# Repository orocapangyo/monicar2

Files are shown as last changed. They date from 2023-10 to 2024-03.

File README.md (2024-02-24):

# Monicar II ROS navigation Robot
This project is about ROS Package for navigation with DIY robot  
Robot 3D model, BOM: Byungki  
Circuit: Byungki, ZETA7    
PCB layout: Byungki   
Aruduino/ESP32 scketch: ZETA7  
ROS code: ZETA7, Alpha, Byungki

## Tested System information

**Jetson Nano 4GB/2GB + RPLidar/YDLidar + ESP32 + DC motor with Encoder**
* Ubuntu 20.04
* ROS2 Galactic

## Packages with Brief Explanation

```
├── monicar2_bringup      => robot bringup, start uROS, RPLidar, IMU...
├── monicar2_cartographer => SLAM via cartographer
├── monicar2_description  => Show robot
├── monicar2_imuconverter => Make /imu/data topic, issues static TF
├── monicar2_localization => issue odometry, make ekfPose
├── monicar2_navigation2  => ros2 navigation2
├── monicar2_teleop       => teleop via keyboard, joystick(=gamepad)
├── arduino               => uROS on ESP32, udev rules, motor tester
(...)
├──
├── Images
├── LICENSE
├── README.md
```
# Especially Thanks
Automatic Addision: https://automaticaddison.com/how-to-set-up-the-ros-navigation-stack-on-a-robot/  
OMO R1 Mini: https://github.com/omorobot/omo_r1mini-foxy    
ROBOTIZ: https://github.com/ROBOTIS-GIT/turtlebot3       
Other Open Source sites   

### Monicar2, it uses ESP32 NodeMcu
```
create_udev_rules_esp32snode.sh, delete_udev_rules_esp32snode.sh, esp32sNodemcu.rules: udev rule for ESP32
create_udev_rules_rplidar.sh, delete_udev_rules_rplidar.sh, rplidar.rules: udev rule for RPLidar

ledBuzzer32Test.ino: Check LED, Buzzer
encoder32Test.ino: Check encoder tick
motorController32Test.ino: Check/Tune motor controller
motorEncLed32Ros.ino: ROS implementation, motor control and LED
motorEncLedMpu32Ros.ino: PROS implementation, motor control, and MPU6050
motorEncExtraRos/motorEncExtraRos.ino
. Please burn this sketch for ROS navigation,
. motorEncLed32Ros.ino + MPU6050 + OLED animation + Buzzer song
```

## Overview   
 <div align="center">
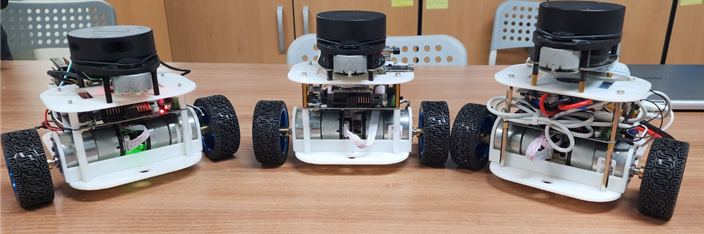
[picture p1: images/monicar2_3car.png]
      
</div>

## Diagram   
<div align="center">
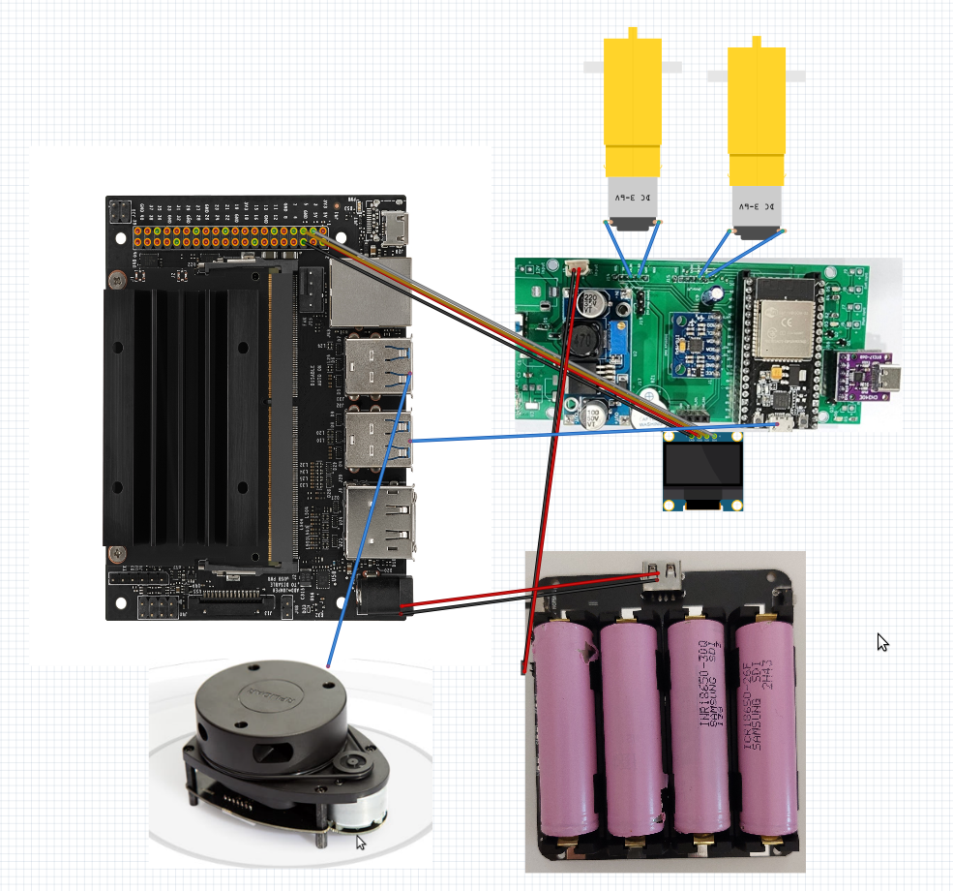
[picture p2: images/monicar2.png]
     
</div>

## Installation
Please download image from below location   
https://drive.google.com/file/d/1Jhr4SIeKLocHbJyeximI-j3mksZNgxN3/view?usp=drive_link

```bash
id: jetson
passwd: jetson
```
Please follow instruction on blow Notion(in Korean)   
https://zeta7.notion.site/Monicar-II-1ae110a410024d2291aba25e90d10875?pvs=4

### Clone source

```bash
  cd {$workspace_path}/src/
  git clone https://github.com/orocapangyo/monicar2.git
  git clone -b $ROS_DISTRO https://github.com/micro-ROS/micro_ros_setup.git
  git clone -b ros2 https://github.com/Slamtec/rplidar_ros.git
```

### Install dependency packages

Following additional packages may be reuqired to be installed.  
- ros-galactic-cartographer-ros ros-galactic-nav2-map-server 
- ros-galactic-rqt-robot-steering ros-galactic-imu-tools 
- ros-galactic-tf2-py ros-galactic-tf2-tools ros-galactic-nav2-bringup ros-galactic-navigation2
```bash
sudo apt install -y ros-galactic-cartographer-ros ros-galactic-nav2-map-server \
ros-galactic-rqt-robot-steering ros-galactic-imu-tools \
ros-galactic-tf2-py ros-galactic-tf2-tools ros-galactic-nav2-bringup ros-galactic-navigation2
```

### Build ROS2 source

- To build

```bash
  cd {$workspace_path}
  colcon build --symlink-install
```

- To enable the built source into ROS2 environment

```bash
  cd {$workspace_path}
  ./install/setup.bash
```

## Play with the robot

- To give authority for driver access to MCU and LiDAR

```bash
cd {$workspace_path}/src/monicar2/monicar2_arduino
./create_udev_rules_esp32snode.sh
./create_udev_rules_rplidar.sh
```

- To teleoperate the robot using **GAMEPAD**
```bash
cd {$workspace_path}
# jetson , terminal 1
$ ros2 launch monicar2_bringup mcu.launch.py
#jetson or pc terminal 2
$ ros2 launch monicar2_teleop teleop_joy.launch.py
```

- To teleoperate the robot using **KEYBOARD**

```bash
cd {$workspace_path}
# jetson , terminal 1
$ ros2 launch monicar2_bringup mcu.launch.py
#jetson or pc terminal 2
$ ros2 run monicar2_teleop teleop_keyboard
```

## SLAM with the robot
To conduct SLAM (Try after few seconds from MCU and LiDAR bringup)
- Cartographer
```bash
cd {$workspace_path}
$ ros2 launch monicar2_localization ekfPose.launch.py
# or using another options
# example) teleop_joy, not using description
$ ros2 launch monicar2_localization ekfPose.launch.py use_joy:='true' use_des:='false'

#terminal #2, recommand PC than Jetson
$ ros2 launch monicar2_cartographer cartographer.launch.py
#terminal #3, recommand PC than Jetson
$ ros2 launch monicar2_cartographer cartographer_rviz.launch.py
```
- Slam_toolbox
```bash
#terminal #1, Jetson
cd {$workspace_path}
$ ros2 launch monicar2_localization ekfPose.launch.py
# or using another options
# example) teleop_joy, not using description
$ ros2 launch monicar2_localization ekfPose.launch.py use_joy:='true' use_des:='false'

#terminal #2,recommand PC than Jetson
$ ros2 launch nav2_bringup navigation_launch.py
#terminal #3,recommand PC than Jetson
$ ros2 launch slam_toolbox online_async_launch.py
#terminal #4, recommand PC than Jetson
$ ros2 launch monicar2_navigation2 slamtoolbox_rviz.launch.py
```

- Once mapping is done, you can create map.pgm and map.yaml file by executing

```bash
cd {$HOME}
ros2 run nav2_map_server map_saver_cli -f map
```

- To conduct path planning & following, close all previsous launch.py
```bash
#terminal #1, Jetson
cd {$workspace_path}
$ ros2 launch monicar2_localization ekfPose.launch.py initPose:='false'
# or using another options
# example) not using description
$ ros2 launch monicar2_localization ekfPose.launch.py initPose='false' use_des:='false'

#terminal #2,recommand PC than Jetson
$ ros2 launch monicar2_navigation2 navigation2.launch.py map:=./mymap.yaml
#terminal #3, recommand PC than Jetson
$ ros2 launch monicar2_navigation2 navigation2_rviz.launch.py
```

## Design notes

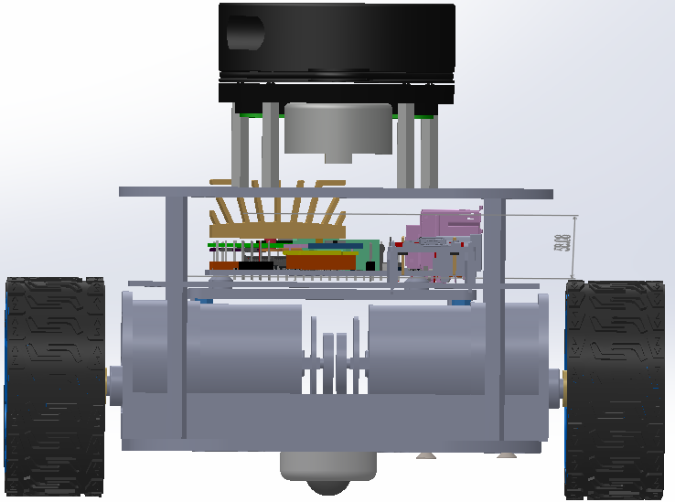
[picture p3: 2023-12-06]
images/monicar2_3d1.png

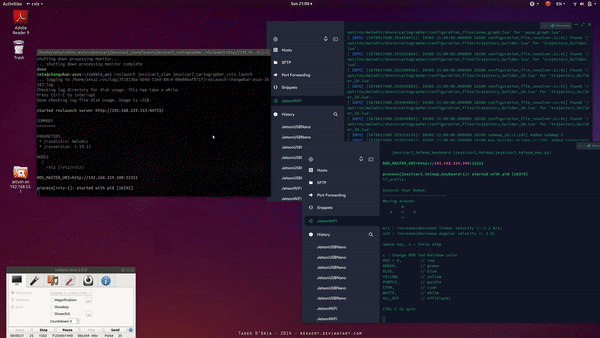
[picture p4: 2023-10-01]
images/cartographer.gif

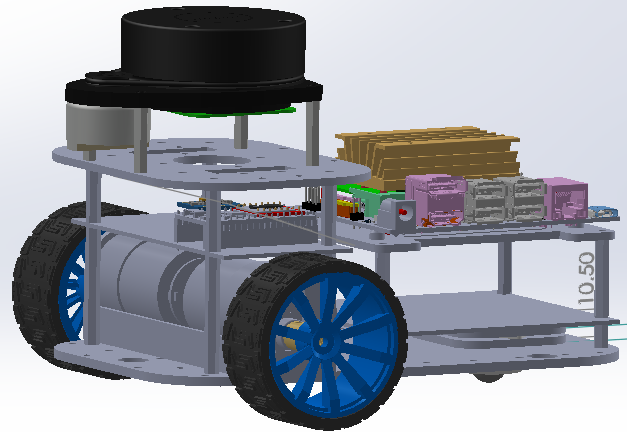
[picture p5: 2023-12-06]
images/monicar2_3d.png

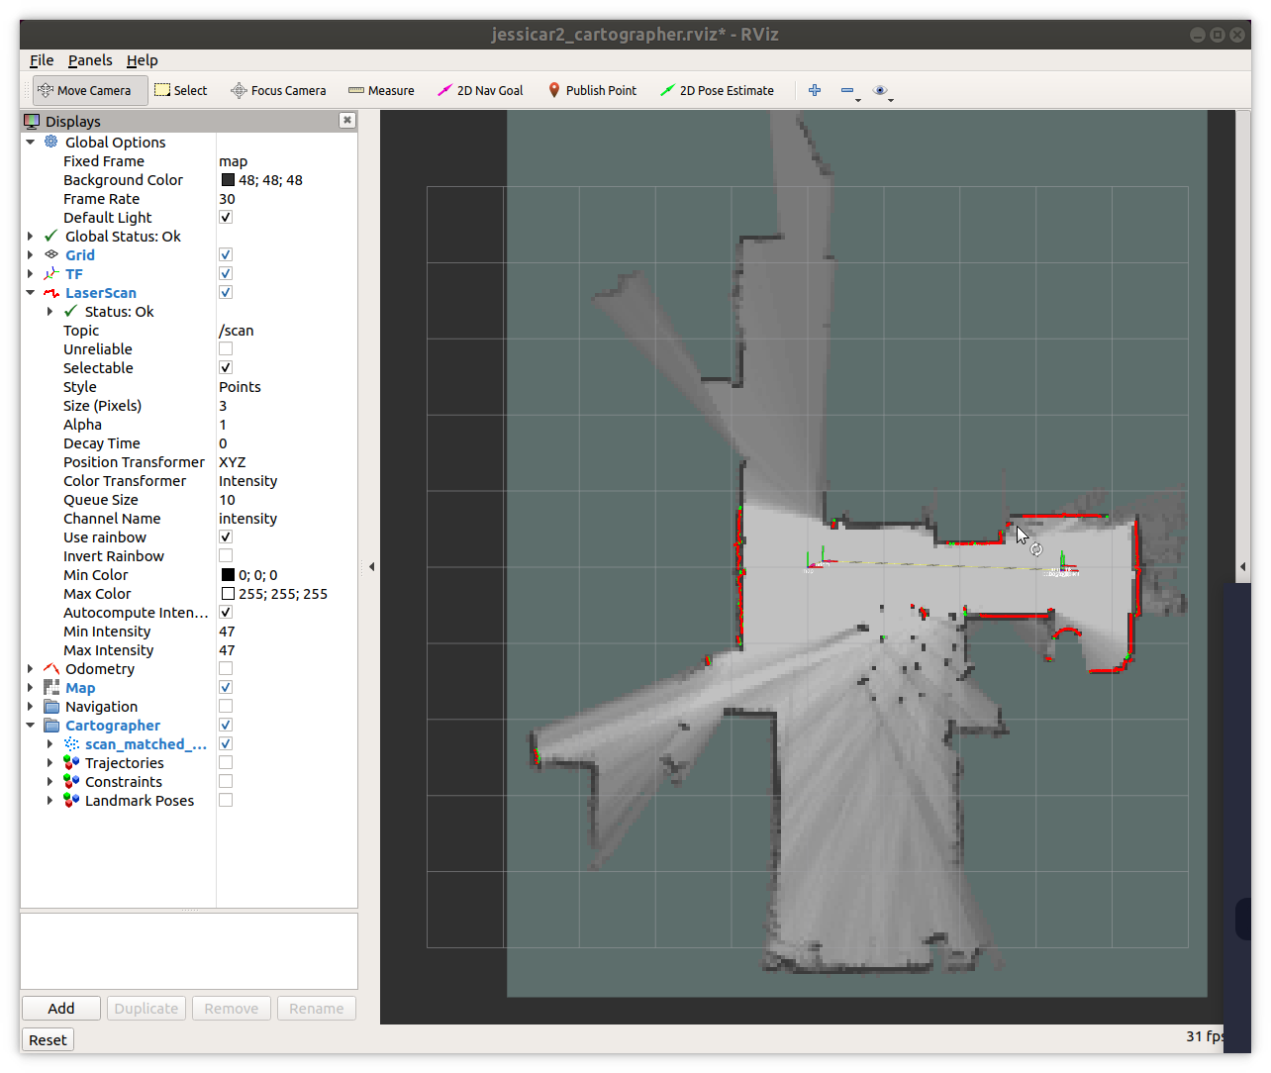
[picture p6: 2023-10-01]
images/cartographer.png

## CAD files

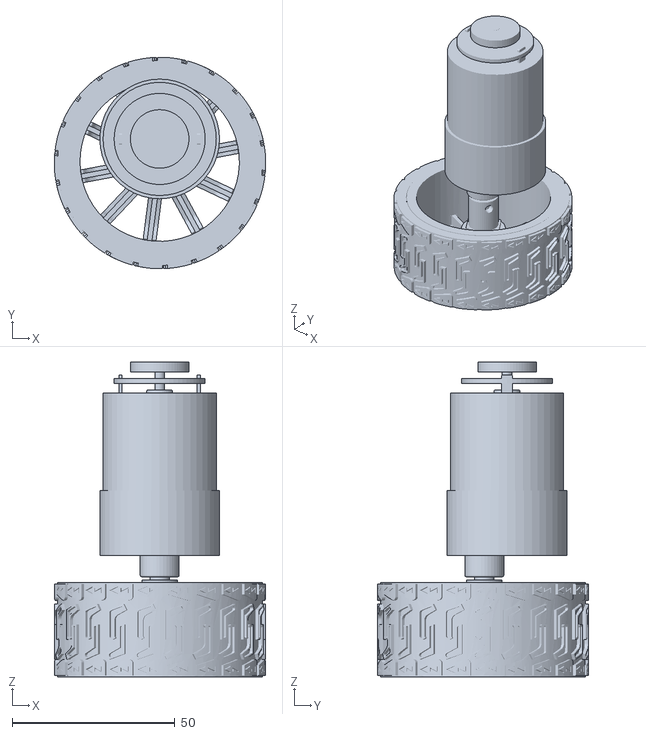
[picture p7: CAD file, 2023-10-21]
monicar2_description/meshes/leftwheel.stl
65.0 x 65.0 x 96.8

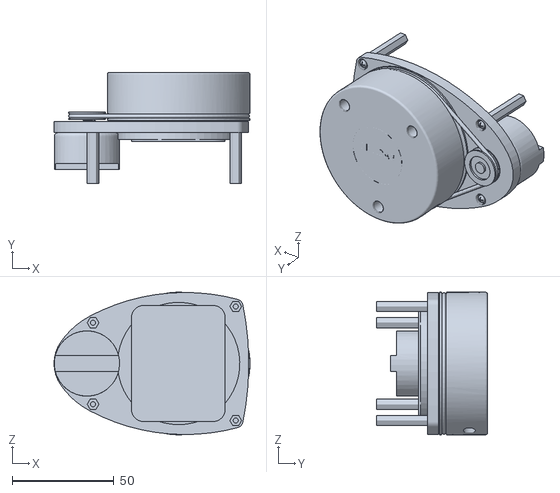
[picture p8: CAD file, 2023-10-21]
monicar2_description/meshes/lidar.stl
96.2 x 54.6 x 70.0

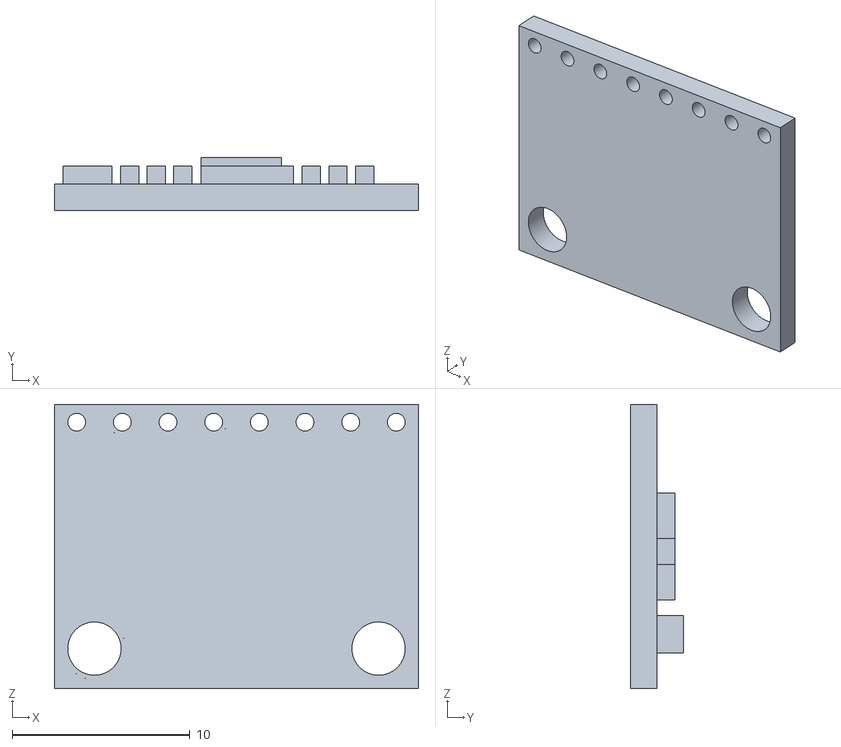
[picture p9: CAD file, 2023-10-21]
monicar2_description/meshes/mpu6050.stl
20.5 x 3.00 x 16.0

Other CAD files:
monicar2_description/meshes/rightwheel.stl

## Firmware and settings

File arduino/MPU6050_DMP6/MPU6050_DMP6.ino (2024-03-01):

// I2C device class (I2Cdev) demonstration Arduino sketch for MPU6050 class using DMP (MotionApps v2.0)
// 6/21/2012 by Jeff Rowberg <jeff@rowberg.net>
// Updates should (hopefully) always be available at https://github.com/jrowberg/i2cdevlib
//
// Changelog:
//      2019-07-08 - Added Auto Calibration and offset generator
//		   - and altered FIFO retrieval sequence to avoid using blocking code
//      2016-04-18 - Eliminated a potential infinite loop
//      2013-05-08 - added seamless Fastwire support
//                 - added note about gyro calibration
//      2012-06-21 - added note about Arduino 1.0.1 + Leonardo compatibility error
//      2012-06-20 - improved FIFO overflow handling and simplified read process
//      2012-06-19 - completely rearranged DMP initialization code and simplification
//      2012-06-13 - pull gyro and accel data from FIFO packet instead of reading directly
//      2012-06-09 - fix broken FIFO read sequence and change interrupt detection to RISING
//      2012-06-05 - add gravity-compensated initial reference frame acceleration output
//                 - add 3D math helper file to DMP6 example sketch
//                 - add Euler output and Yaw/Pitch/Roll output formats
//      2012-06-04 - remove accel offset clearing for better results (thanks Sungon Lee)
//      2012-06-01 - fixed gyro sensitivity to be 2000 deg/sec instead of 250
//      2012-05-30 - basic DMP initialization working

/* ============================================
I2Cdev device library code is placed under the MIT license
Copyright (c) 2012 Jeff Rowberg

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
THE SOFTWARE IS PROVIDED "AS IS", WITHOUT WARRANTY OF ANY KIND, EXPRESS OR
IMPLIED, INCLUDING BUT NOT LIMITED TO THE WARRANTIES OF MERCHANTABILITY,
FITNESS FOR A PARTICULAR PURPOSE AND NONINFRINGEMENT. IN NO EVENT SHALL THE
AUTHORS OR COPYRIGHT HOLDERS BE LIABLE FOR ANY CLAIM, DAMAGES OR OTHER
LIABILITY, WHETHER IN AN ACTION OF CONTRACT, TORT OR OTHERWISE, ARISING FROM,
OUT OF OR IN CONNECTION WITH THE SOFTWARE OR THE USE OR OTHER DEALINGS IN
THE SOFTWARE.
===============================================
*/

// I2Cdev and MPU6050 must be installed as libraries, or else the .cpp/.h files
// for both classes must be in the include path of your project
#include "I2Cdev.h"

#include "MPU6050_6Axis_MotionApps20.h"
//#include "MPU6050.h" // not necessary if using MotionApps include file

// Arduino Wire library is required if I2Cdev I2CDEV_ARDUINO_WIRE implementation
// is used in I2Cdev.h
#if I2CDEV_IMPLEMENTATION == I2CDEV_ARDUINO_WIRE
#include "Wire.h"
#endif

// class default I2C address is 0x68
// specific I2C addresses may be passed as a parameter here
// AD0 low = 0x68 (default for SparkFun breakout and InvenSense evaluation board)
// AD0 high = 0x69
MPU6050 mpu;
//MPU6050 mpu(0x69); // <-- use for AD0 high

/* =========================================================================
   NOTE: In addition to connection 3.3v, GND, SDA, and SCL, this sketch
   depends on the MPU-6050's INT pin being connected to the Arduino's
   external interrupt #0 pin. On the Arduino Uno and Mega 2560, this is
   digital I/O pin 2.
 * ========================================================================= */

/* =========================================================================
   NOTE: Arduino v1.0.1 with the Leonardo board generates a compile error
   when using Serial.write(buf, len). The Teapot output uses this method.
   The solution requires a modification to the Arduino USBAPI.h file, which
   is fortunately simple, but annoying. This will be fixed in the next IDE
   release. For more info, see these links:

   http://arduino.cc/forum/index.php/topic,109987.0.html
   http://code.google.com/p/arduino/issues/detail?id=958
 * ========================================================================= */

long previousMillis = 0;
long currentMillis = 0;
#define INTERVAL 50  //50ms, so 20Hz

// uncomment "OUTPUT_READABLE_QUATERNION" if you want to see the actual
// quaternion components in a [w, x, y, z] format (not best for parsing
// on a remote host such as Processing or something though)
#define OUTPUT_READABLE_QUATERNION

// uncomment "OUTPUT_READABLE_EULER" if you want to see Euler angles
// (in degrees) calculated from the quaternions coming from the FIFO.
// Note that Euler angles suffer from gimbal lock (for more info, see
// http://en.wikipedia.org/wiki/Gimbal_lock)
//#define OUTPUT_READABLE_EULER

// uncomment "OUTPUT_READABLE_YAWPITCHROLL" if you want to see the yaw/
// pitch/roll angles (in degrees) calculated from the quaternions coming
// from the FIFO. Note this also requires gravity vector calculations.
// Also note that yaw/pitch/roll angles suffer from gimbal lock (for
// more info, see: http://en.wikipedia.org/wiki/Gimbal_lock)
//#define OUTPUT_READABLE_YAWPITCHROLL

// uncomment "OUTPUT_READABLE_REALACCEL" if you want to see acceleration
// components with gravity removed. This acceleration reference frame is
// not compensated for orientation, so +X is always +X according to the
// sensor, just without the effects of gravity. If you want acceleration
// compensated for orientation, us OUTPUT_READABLE_WORLDACCEL instead.
//#define OUTPUT_READABLE_REALACCEL

// uncomment "OUTPUT_READABLE_WORLDACCEL" if you want to see acceleration
// components with gravity removed and adjusted for the world frame of
// reference (yaw is relative to initial orientation, since no magnetometer
// is present in this case). Could be quite handy in some cases.
//#define OUTPUT_READABLE_WORLDACCEL

// uncomment "OUTPUT_TEAPOT" if you want output that matches the
// format used for the InvenSense teapot demo
//#define OUTPUT_TEAPOT

#define MPU_INT 12  // use pin 2 on Arduino Uno & most boards
bool blinkState = false;

// orientation/motion vars
Quaternion q;         // [w, x, y, z]         quaternion container
VectorInt16 aa;       // [x, y, z]            accel sensor measurements
VectorInt16 aaReal;   // [x, y, z]            gravity-free accel sensor measurements
VectorInt16 aaWorld;  // [x, y, z]            world-frame accel sensor measurements
VectorFloat gravity;  // [x, y, z]            gravity vector
float euler[3];       // [psi, theta, phi]    Euler angle container
float ypr[3];         // [yaw, pitch, roll]   yaw/pitch/roll container and gravity vector

// packet structure for InvenSense teapot demo
uint8_t teapotPacket[14] = { '$', 0x02, 0, 0, 0, 0, 0, 0, 0, 0, 0x00, 0x00, '\r', '\n' };

// ================================================================
// ===               INTERRUPT DETECTION ROUTINE                ===
// ================================================================

volatile bool mpuInterrupt = false;  // indicates whether MPU interrupt pin has gone high
// MPU control/status vars
bool dmpReady = false;  // set true if DMP init was successfu
uint8_t mpuIntStatus;   // holds actual interrupt status byte from MPU
// MPU control/status vars
uint8_t devStatus;       // return status after each device operation (0 = success, !0 = error)
uint16_t packetSize;     // expected DMP packet size (default is 42 bytes)
uint16_t fifoCount;      // count of all bytes currently in FIFO
uint8_t fifoBuffer[64];  // FIFO storage buffer

void ICACHE_RAM_ATTR dmpDataReady() {
  mpuInterrupt = true;
}

// ================================================================
// ===                      INITIAL SETUP                       ===
// ================================================================

void setup() {
// join I2C bus (I2Cdev library doesn't do this automatically)
#if I2CDEV_IMPLEMENTATION == I2CDEV_ARDUINO_WIRE
  Wire.begin();
  Wire.setClock(400000);  // 400kHz I2C clock. Comment this line if having compilation difficulties
#elif I2CDEV_IMPLEMENTATION == I2CDEV_BUILTIN_FASTWIRE
  Fastwire::setup(400, true);
#endif

  // initialize serial communication
  // (115200 chosen because it is required for Teapot Demo output, but it's
  // really up to you depending on your project)
  Serial.begin(115200);
  while (!Serial)
    ;  // wait for Leonardo enumeration, others continue immediately

  // NOTE: 8MHz or slower host processors, like the Teensy @ 3.3V or Arduino
  // Pro Mini running at 3.3V, cannot handle this baud rate reliably due to
  // the baud timing being too misaligned with processor ticks. You must use
  // 38400 or slower in these cases, or use some kind of external separate
  // crystal solution for the UART timer.

  // initialize device
  Serial.println(F("Initializing I2C devices..."));
  mpu.initialize();
  pinMode(MPU_INT, INPUT);

  // verify connection
  Serial.println(F("Testing device connections..."));
  Serial.println(mpu.testConnection() ? F("MPU6050 connection successful") : F("MPU6050 connection failed"));

  // wait for ready
  Serial.println(F("\nSend any character to begin DMP programming and demo: "));

  // load and configure the DMP
  Serial.println(F("Initializing DMP..."));
  devStatus = mpu.dmpInitialize();

  // supply your own gyro offsets here, scaled for min sensitivity
  mpu.setXGyroOffset(103);
  mpu.setYGyroOffset(20);
  mpu.setZGyroOffset(0);
  mpu.setZAccelOffset(595);  // 1688 factory default for my test chip

  // make sure it worked (returns 0 if so)
  if (devStatus == 0) {
    // Calibration Time: generate offsets and calibrate our MPU6050
    mpu.CalibrateAccel(6);
    mpu.CalibrateGyro(6);
    mpu.PrintActiveOffsets();
    // turn on the DMP, now that it's ready
    Serial.println(F("Enabling DMP..."));
    mpu.setDMPEnabled(true);

    // enable Arduino interrupt detection
    Serial.print(F("Enabling interrupt detection (Arduino external interrupt "));
    Serial.print(digitalPinToInterrupt(MPU_INT));
    Serial.println(F(")..."));
    attachInterrupt(digitalPinToInterrupt(MPU_INT), dmpDataReady, RISING);
    mpuIntStatus = mpu.getIntStatus();

    // set our DMP Ready flag so the main loop() function knows it's okay to use it
    Serial.println(F("DMP ready! Waiting for first interrupt..."));
    dmpReady = true;

    // get expected DMP packet size for later comparison
    packetSize = mpu.dmpGetFIFOPacketSize();
  } else {
    // ERROR!
    // 1 = initial memory load failed
    // 2 = DMP configuration updates failed
    // (if it's going to break, usually the code will be 1)
    Serial.print(F("DMP Initialization failed (code "));
    Serial.print(devStatus);
    Serial.println(F(")"));
  }

  // configure LED for output
  pinMode(LED_BUILTIN, OUTPUT);
}

// ================================================================
// ===                    MAIN PROGRAM LOOP                     ===
// ================================================================

void loop() {
  // if programming failed, don't try to do anything
  if (!dmpReady) return;
  // wait for MPU interrupt or extra packet(s) available
  if (!mpuInterrupt) return;

  // reset interrupt flag and get INT_STATUS byte
  mpuInterrupt = false;
  mpuIntStatus = mpu.getIntStatus();

  // read a packet from FIFO
  if (mpu.dmpGetCurrentFIFOPacket(fifoBuffer)) {  // Get the Latest packet
#ifdef OUTPUT_READABLE_QUATERNION
    // display quaternion values in easy matrix form: w x y z
    mpu.dmpGetQuaternion(&q, fifoBuffer);
    Serial.print("quat\t");
    Serial.print(q.w);
    Serial.print("\t");
    Serial.print(q.x);
    Serial.print("\t");
    Serial.print(q.y);
    Serial.print("\t");
    Serial.println(q.z);
#endif

#ifdef OUTPUT_READABLE_EULER
    // display Euler angles in degrees
    mpu.dmpGetQuaternion(&q, fifoBuffer);
    mpu.dmpGetEuler(euler, &q);
    Serial.print("euler\t");
    Serial.print(euler[0] * 180 / M_PI);
    Serial.print("\t");
    Serial.print(euler[1] * 180 / M_PI);
    Serial.print("\t");
    Serial.println(euler[2] * 180 / M_PI);
#endif

#ifdef OUTPUT_READABLE_YAWPITCHROLL
    // display Euler angles in degrees
    mpu.dmpGetQuaternion(&q, fifoBuffer);
    mpu.dmpGetGravity(&gravity, &q);
    mpu.dmpGetYawPitchRoll(ypr, &q, &gravity);
    Serial.print("ypr\t");
    Serial.print(ypr[0] * 180 / M_PI);
    Serial.print("\t");
    Serial.print(ypr[1] * 180 / M_PI);
    Serial.print("\t");
    Serial.println(ypr[2] * 180 / M_PI);
#endif

#ifdef OUTPUT_READABLE_REALACCEL
    // display real acceleration, adjusted to remove gravity
    mpu.dmpGetQuaternion(&q, fifoBuffer);
    mpu.dmpGetAccel(&aa, fifoBuffer);
    mpu.dmpGetGravity(&gravity, &q);
    mpu.dmpGetLinearAccel(&aaReal, &aa, &gravity);
    Serial.print("areal\t");
    Serial.print(aaReal.x);
    Serial.print("\t");
    Serial.print(aaReal.y);
    Serial.print("\t");
    Serial.println(aaReal.z);
#endif

#ifdef OUTPUT_READABLE_WORLDACCEL
    // display initial world-frame acceleration, adjusted to remove gravity
    // and rotated based on known orientation from quaternion
    mpu.dmpGetQuaternion(&q, fifoBuffer);
    mpu.dmpGetAccel(&aa, fifoBuffer);
    mpu.dmpGetGravity(&gravity, &q);
    mpu.dmpGetLinearAccel(&aaReal, &aa, &gravity);
    mpu.dmpGetLinearAccelInWorld(&aaWorld, &aaReal, &q);
    Serial.print("aworld\t");
    Serial.print(aaWorld.x);
    Serial.print("\t");
    Serial.print(aaWorld.y);
    Serial.print("\t");
    Serial.println(aaWorld.z);
#endif

#ifdef OUTPUT_TEAPOT
    // display quaternion values in InvenSense Teapot demo format:
    teapotPacket[2] = fifoBuffer[0];
    teapotPacket[3] = fifoBuffer[1];
    teapotPacket[4] = fifoBuffer[4];
    teapotPacket[5] = fifoBuffer[5];
    teapotPacket[6] = fifoBuffer[8];
    teapotPacket[7] = fifoBuffer[9];
    teapotPacket[8] = fifoBuffer[12];
    teapotPacket[9] = fifoBuffer[13];
    Serial.write(teapotPacket, 14);
    teapotPacket[11]++;  // packetCount, loops at 0xFF on purpose
#endif
    // Record the time
    currentMillis = millis();
    // If the time interval has passed, publish the number of ticks,
    // and calculate the velocities.
    if (currentMillis - previousMillis > INTERVAL) {
      previousMillis = currentMillis;
      // blink LED to indicate activity
      blinkState = !blinkState;
      digitalWrite(LED_BUILTIN, blinkState);
    }
  }
}

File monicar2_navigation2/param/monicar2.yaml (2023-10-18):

amcl:
  ros__parameters:
    use_sim_time: False
    alpha1: 0.2
    alpha2: 0.2
    alpha3: 0.2
    alpha4: 0.2
    alpha5: 0.2
    base_frame_id: "base_footprint"
    beam_skip_distance: 0.5
    beam_skip_error_threshold: 0.9
    beam_skip_threshold: 0.3
    do_beamskip: false
    global_frame_id: "map"
    lambda_short: 0.1
    laser_likelihood_max_dist: 2.0
    laser_max_range: 10.0
    laser_min_range: 0.12
    laser_model_type: "likelihood_field"
    max_beams: 60
    max_particles: 2000
    min_particles: 500
    odom_frame_id: "odom"
    pf_err: 0.05
    pf_z: 0.99
    recovery_alpha_fast: 0.0
    recovery_alpha_slow: 0.0
    resample_interval: 1
    robot_model_type: "differential"
    save_pose_rate: 0.5
    sigma_hit: 0.2
    tf_broadcast: true
    transform_tolerance: 1.0
    update_min_a: 0.2
    update_min_d: 0.25
    z_hit: 0.5
    z_max: 0.05
    z_rand: 0.5
    z_short: 0.05
    scan_topic: scan

amcl_map_client:
  ros__parameters:
    use_sim_time: False

amcl_rclcpp_node:
  ros__parameters:
    use_sim_time: False

bt_navigator:
  ros__parameters:
    use_sim_time: False
    global_frame: map
    robot_base_frame: base_link
    odom_topic: /odom
    bt_loop_duration: 10
    default_server_timeout: 20
    # 'default_nav_through_poses_bt_xml' and 'default_nav_to_pose_bt_xml' are use defaults:
    # nav2_bt_navigator/navigate_to_pose_w_replanning_and_recovery.xml
    # nav2_bt_navigator/navigate_through_poses_w_replanning_and_recovery.xml
    # They can be set here or via a RewrittenYaml remap from a parent launch file to Nav2.
    plugin_lib_names:
    - nav2_compute_path_to_pose_action_bt_node
    - nav2_compute_path_through_poses_action_bt_node
    - nav2_follow_path_action_bt_node
    - nav2_back_up_action_bt_node
    - nav2_spin_action_bt_node
    - nav2_wait_action_bt_node
    - nav2_clear_costmap_service_bt_node
    - nav2_is_stuck_condition_bt_node
    - nav2_goal_reached_condition_bt_node
    - nav2_goal_updated_condition_bt_node
    - nav2_initial_pose_received_condition_bt_node
    - nav2_reinitialize_global_localization_service_bt_node
    - nav2_rate_controller_bt_node
    - nav2_distance_controller_bt_node
    - nav2_speed_controller_bt_node
    - nav2_truncate_path_action_bt_node
    - nav2_goal_updater_node_bt_node
    - nav2_recovery_node_bt_node
    - nav2_pipeline_sequence_bt_node
    - nav2_round_robin_node_bt_node
    - nav2_transform_available_condition_bt_node
    - nav2_time_expired_condition_bt_node
    - nav2_distance_traveled_condition_bt_node
    - nav2_single_trigger_bt_node
    - nav2_is_battery_low_condition_bt_node
    - nav2_navigate_through_poses_action_bt_node
    - nav2_navigate_to_pose_action_bt_node
    - nav2_remove_passed_goals_action_bt_node
    - nav2_planner_selector_bt_node
    - nav2_controller_selector_bt_node
    - nav2_goal_checker_selector_bt_node

bt_navigator_rclcpp_node:
  ros__parameters:
    use_sim_time: False

controller_server:
  ros__parameters:
    use_sim_time: False
    controller_frequency: 10.0
    min_x_velocity_threshold: 0.001
    min_y_velocity_threshold: 0.5
    min_theta_velocity_threshold: 0.001
    failure_tolerance: 0.3
    progress_checker_plugin: "progress_checker"
    goal_checker_plugins: ["general_goal_checker"]
    controller_plugins: ["FollowPath"]

    # Progress checker parameters
    progress_checker:
      plugin: "nav2_controller::SimpleProgressChecker"
      required_movement_radius: 0.5
      movement_time_allowance: 10.0
    # Goal checker parameters
    general_goal_checker:
      stateful: True
      plugin: "nav2_controller::SimpleGoalChecker"
      xy_goal_tolerance: 0.25
      yaw_goal_tolerance: 0.25
    # DWB parameters
    FollowPath:
      plugin: "dwb_core::DWBLocalPlanner"
      debug_trajectory_details: True
      min_vel_x: -0.18
      min_vel_y: 0.0
      max_vel_x: 0.18
      max_vel_y: 0.0
      max_vel_theta: 1.7
      min_speed_xy: 0.0
      max_speed_xy: 0.30
      min_speed_theta: 0.0
      acc_lim_x: 0.1
      acc_lim_y: 0.0
      acc_lim_theta: 1.0
      decel_lim_x: -0.1
      decel_lim_y: 0.0
      decel_lim_theta: -1.0
      vx_samples: 20
      vy_samples: 5
      vtheta_samples: 20
      sim_time: 1.7
      linear_granularity: 0.05
      angular_granularity: 0.025
      transform_tolerance: 0.1 #0.2
      xy_goal_tolerance: 0.05 #0.25
      trans_stopped_velocity: 0.25
      short_circuit_trajectory_evaluation: True
      stateful: True
      critics: ["RotateToGoal", "Oscillation", "BaseObstacle", "GoalAlign", "PathAlign", "PathDist", "GoalDist"]
      BaseObstacle.scale: 0.02
      PathAlign.scale: 32.0
      PathAlign.forward_point_distance: 0.1
      GoalAlign.scale: 24.0
      GoalAlign.forward_point_distance: 0.1
      PathDist.scale: 32.0
      GoalDist.scale: 24.0
      RotateToGoal.scale: 32.0
      RotateToGoal.slowing_factor: 5.0
      RotateToGoal.lookahead_time: -1.0

controller_server_rclcpp_node:
  ros__parameters:
    use_sim_time: False
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

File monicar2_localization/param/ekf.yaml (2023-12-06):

### ekf config file ###
ekf_filter_node:
    ros__parameters:
        use_sim_time: false
        
# The frequency, in Hz, at which the filter will output a position estimate. Note that the filter will not begin
# computation until it receives at least one message from one of the inputs. It will then run continuously at the
# frequency specified here, regardless of whether it receives more measurements. Defaults to 30 if unspecified.
        frequency: 20.0

# The period, in seconds, after which we consider a sensor to have timed out. In this event, we carry out a predict
# cycle on the EKF without correcting it. This parameter can be thought of as the minimum frequency with which the
# filter will generate new output. Defaults to 1 / frequency if not specified.
        sensor_timeout: 0.1

# ekf_localization_node and ukf_localization_node both use a 3D omnidirectional motion model. If this parameter is
# set to true, no 3D information will be used in your state estimate. Use this if you are operating in a planar
# environment and want to ignore the effect of small variations in the ground plane that might otherwise be detected
# by, for example, an IMU. Defaults to false if unspecified.
        two_d_mode: true

# Use this parameter to provide an offset to the transform generated by ekf_localization_node. This can be used for
# future dating the transform, which is required for interaction with some other packages. Defaults to 0.0 if
# unspecified.
        transform_time_offset: 0.0

# Use this parameter to provide specify how long the tf listener should wait for a transform to become available. 
# Defaults to 0.0 if unspecified.
        transform_timeout: 0.0

# If you're having trouble, try setting this to true, and then echo the /diagnostics_agg topic to see if the node is
# unhappy with any settings or data.
        print_diagnostics: true

# Debug settings. Not for the faint of heart. Outputs a ludicrous amount of information to the file specified by
# debug_out_file. I hope you like matrices! Please note that setting this to true will have strongly deleterious
# effects on the performance of the node. Defaults to false if unspecified.
        debug: false

# Defaults to "robot_localization_debug.txt" if unspecified. Please specify the full path.
        debug_out_file: /path/to/debug/file.txt

# Whether to broadcast the transformation over the /tf topic. Defaults to true if unspecified.
        publish_tf: true

# Whether to publish the acceleration state. Defaults to false if unspecified.
        publish_acceleration: false

# If the filter sees a jump back in time, the filter is reset (convenient for testing with rosbags!)
        reset_on_time_jump: true

# REP-105 (http://www.ros.org/reps/rep-0105.html) specifies four principal coordinate frames: base_link, odom, map, and
# earth. base_link is the coordinate frame that is affixed to the robot. Both odom and map are world-fixed frames.
# The robot's position in the odom frame will drift over time, but is accurate in the short term and should be
# continuous. The odom frame is therefore the best frame for executing local motion plans. The map frame, like the odom
# frame, is a world-fixed coordinate frame, and while it contains the most globally accurate position estimate for your
# robot, it is subject to discrete jumps, e.g., due to the fusion of GPS data or a correction from a map-based
# localization node. The earth frame is used to relate multiple map frames by giving them a common reference frame.
# ekf_localization_node and ukf_localization_node are not concerned with the earth frame.
# Here is how to use the following settings:
# 1. Set the map_frame, odom_frame, and base_link frames to the appropriate frame names for your system.
#     1a. If your system does not have a map_frame, just remove it, and make sure "world_frame" is set to the value of
#         odom_frame.
# 2. If you are fusing continuous position data such as wheel encoder odometry, visual odometry, or IMU data, set
#   "world_frame" to your odom_frame value. This is the default behavior for robot_localization's state estimation nodes.
# 3. If you are fusing global absolute position data that is subject to discrete jumps (e.g., GPS or position updates
# from landmark observations) then:
#     3a. Set your "world_frame" to your map_frame value
#     3b. MAKE SURE something else is generating the odom->base_link transform. Note that this can even be another state
#         estimation node from robot_localization! However, that instance should *not* fuse the global data.
        map_frame: map                   # Defaults to "map" if unspecified
        odom_frame: odom                 # Defaults to "odom" if unspecified
        base_link_frame: base_footprint  # Defaults to "base_link" if unspecified
        world_frame: odom                # Defaults to the value of odom_frame if unspecified
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

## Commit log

2023-08-09 Add blank file for urdf folder missing
2023-08-17 lidar, mcu launch implement
    1. Makes lidar, mcu launch.py
    2. Delete all srv
    3. Fix warnings for script-dir, install-scripts
    4. mcu.yaml, lidar.yaml -> no function yet
    5. Add rviz of rplidar launch.py
2023-08-18 Implement LED ROS, Encoder ROS
    1. Implement LED, Encoder for micro-ros
    2. Delete old Arduino Nano rules and test code
2023-08-20 Implement other micro ROS code
    1. Implement Enc/Motor/LED/MPU6050 micro ROS
    2. Implement Enc/Motor/LEDmicro ROS
2023-09-02 Implement odom publisher and imu_converter
    1. Implement odom publisher with python
    Add launch.py into monicar2_bringup
    2. Implement imu_converter with python
    Add launch.py
2023-09-03 Add sendTransform into imuconverter
    1. Add sendTransform for base_link -> imu_link
    2. Change RVIZ2 parameter
2023-09-05 Implement monicar2_localization
    1. Make monicar2_localization package
    - move monicar2_odom.py to monicar2_localization, and change name to odomPublisher.py
    - Implement rivz2ClickTo2d.py
    - Add launch.py, initPoseRviz2.launch.py and rviz2ClickTo2d.launch.py
    2. Rename imucnoverter.py, truncate monicar2
2023-09-09 Implement odom publisher, fix a imuconverter rviz
    1. odomPublisher.py works now
    2. Add initPoseRviz2, odomPublisher launch.py, read yaml files
    3. Fix a typo in mpu6050_imu_rviz.launch.py
    Add box property to rviz
2023-09-10 Add static_transform_publisher
    1. Add static_transform_publisher into bringup.launch.py
    2. Use simple name, so remove monicar2_ from file name
    3. Change lidar frame_id laser -> laser_link
    4. Add initial_2d subscriber, init2dCallback into odomPublisher
    Change frame_id, then odom -> base_footprint
    5. set correct value for imu translation
2023-09-13 Implement averaging PWM
    1. Delete Kbias, apply tuned parameter
    2. Implement averaging PWM
    if reach +/-2% target, then start to average, moving average 10 times
2023-09-16 Add 620 pulse motor support
    *Ros32.ino
    1. Tune 620 tick motor parameter
    -> Need to select motor type, default is 1860 tick
    620 tick motor goes main loop slower
    620 tick motor bias is severe
    2. Change PID gain
    3. PWM_INCREMENT 8 if starts from 0. then set to 1 if approach target. If not set 1, PID can't start
    4. Remove "stop the car before switching direction", since motor starts, sometimes velocity is reverse
    5. buzzer on if both motors are reverse
    6. Add more debug
    *32Test.ino
    1. Tune 620 tick motor parameter
    -> Need to select motor type, default is 1860 tick
    620 tick motor bias is severe
    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
    [motorController32Test.ino]
2023-09-16 Add ledpub&edit yaml(speed down)
2023-09-17 Update motorEncLedMpuRos32.ino
    Fix "esp32 reset required to join micro_ros_agent. Separate create_entities from setup, then add destroy_entities. rcl_publish run without RCSOFTCHECK
2023-09-17 Revert "Update motorEncLedMpuRos32.ino"
    This reverts commit 3aa638d3f675ba977c1cc9252f80ed04895a1c0b.
2023-09-18 Make a new way not to press reset with ESP32
    1. rmw_uros_ping_agent(100, 1)) caused a lot of delay, reduce this time
    2. wait at setup for agent, then escape setup if agent comes up
    3. if agent close, then reboot esp32
    4. delete unused code for imuconverter.py
    5. Add rviz2_click_node for ekfPose.launch.py
2023-09-25 cartographer works with minor error log
    1. Remove static_transform_publisher from launch.py. Somehow it can't publish if I use two tf.
    2. Implement 2 tf into imuconvert.py
    quaternion publish with timer, previous it publish whenever quaternion comes in
    3. Mix with previous version of odomPublsiher.py, somehow cartographer didn't work.
    4. Add setup.cfg, setup.py into navigation2
2023-10-01 Support two motors
    1. add selMotor.sh, low rpm or high rpm
    odomPublisher read TPR parameter from yaml
    2. Update README
    And add pictures
2023-10-02 1'st version which can navigate on Galactic
    1. change navigation2 parameter, refer to automatic addison
    Run well with Galactic
    2. change motor type, MOTOR_1860 -> MOTOR_60RPM, MOTOR_620->MOTOR_178RPM
    3. esp32 for Galactic, because node_ops.domain_id cause error with Galactic
    4. Somehow parameters with None caused error
    [monicar2.yaml, motorController32Test.ino]
2023-10-03 Tune navigation2 parameter
    1. Tune navigation2 parameter
    2. sleMotor.sh change esp32 ino file as well, add MOTOR_TYPE swap feature
    [monicar2.yaml]
2023-10-07 Fix an error that RVIZ can't draw scan on Jetson
    Need to load monicar2_bringup/rviz/rplidar.rviz
2023-10-14 Fix parameters None related error
    1. None -> specific value which matches to type
    2. Use imu.yaml for imuconverter
    3. Update keyboard.param.yaml, but still don't use
2023-10-17 Delete unused import, add emulate_tty from *.launch.py. emulate_tty makes real time print
    1. Delete unused import, add emulate_tty from *.launch.py. emulate_tty makes real time print
    2. Fix move.py, rotate.py for both direction. Add int()
    3. Add timer_tick parameter in odomPublisher, initialPose -> initPoseRecieved
    4. Add maker faire map
    5. Change rviz of navigation2, nav2_default_view.rviz -> monicar2_navigation2.rviz
    [monicar2.yaml]
2023-10-21 Implement robot description
    1. Implement monicar2_description
    Use total.stl only
    => Then include description.launch.py from ekfPose.launch.py, ekfPose4map.launch.py, navigation2.launch.py
    Of course, RobotModel is included in rviz
    2. teleop_joy.py axces changes
    3. Change IMU offset , add define DOMAINID, loop 33Hz -> 20Hz => motorEncLedMpuRos32.ino
    [leftwheel.stl, lidar.stl, mpu6050.stl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]
2023-10-29 Add no ekf launch file
    1. rename navigation2.simple.launch.py -> navigation2_simple.launch.py
    2. Add ekfPose_simple.launch.py
    3. If IMU disable, don't broadcast transform
2023-11-04 Trim launch.py
    1. create efknode. Make odomPubInit0/1, then select it from ekfPose
    efkPose has launch parameters, initPose, use_ekf, use_des, use_joy
    navigation2 has launch parameter, use_des
    2. Fix ekf error, frequency 0 ->20Hz
    [ekf.yaml]
2023-11-25 use_des true, use_ekf delete
    1. Delete use_ekf. robot rotate continuous if turn on ekf_node
    2. use_des true by default
    3. Reduce total.stl size to reduce loading time
    4. Even don't use ekf_node, change ekf parameter not using IMU
    5. Add robot on slamtoolbox rviz
    6. delete remappings from cratographer lauch, not using ekf_node
    [robot.urdf]
2023-11-25 Make launch.py use parameter
    1. Merge odomPubInit0/1 -> odomPubInit, instead use parameters
    2. Merge and rename initPose0/1 -> robot.yaml
    3. ekfPose.launch.py use launch_arguments. So it is possible to merge odomPubInit0/1
    4. mpu6050.launch.py use parameters
    5. imu_enable -> useImu, integer -> BOOL
    6. initPoseRecieved, integer -> BOOL
    [robot.yaml]
2023-12-10 Implement oled animation and buzzer song
    1. led animation and buzzer song.
    1 ino -> 2 ino, 1 h files
    keyboard, joystick python code to start led animation and buzzer song
    2. version 0.0.1 -> 0.9.1
    3. Delete imu.yaml
    4. Update README
    [motorEncExtraRos32.ino, songlcdled.h]
2023-12-12 Fix reboot of ESP32 if wrong value is subscribed
    1. Fix reboot of ESP32 if wrong value is subscribed. Add mod calculation
    song = song % MAX_SONG;
    idx = idx % MAX_ANIM;
    2. Change LED behavoir
    3. Correct wrong condition, songIdx>MAXSONG -> songIdx >= MAX_SONG
    lcdIdx>MAXANIM ->lcdIdx >= MAX_ANIM
    4. Delete white space, due to vscode plugin
    [motorEncExtraRos32.ino, songlcdled.h]
2023-12-14 Add lidar select script
    1. Add selLidar.sh
    2. Increase chattering time 3 -> 5
2023-12-19 Fix wrong frame name of YDLIdar
    1. laser_frame -> laser_link
    2. Change Reliability Policy Reliable -> Best Effort. RVIZ couldn't show laser scan
2024-01-18 Support 178RPM motor all ino code
    1. Add 178RPM motor overall Arduino code. Need to use TOP->Bottom cable
    2. Add set domain_id shell script
    Modify shell script to change all ino files
    3. Increase angle max vel since 178RPM motor doesn't turn
    4. Reduce RPM because false interrupt happens too much
    4. Remove two ino files, too hard to manage through Github
    5. Update several *ros.ino from Foxy -> Galactic
    [encoder32Test.ino, motorController32Test.ino, motorEncExtraRos32.ino]
2024-01-18 Remove exit code in shell sript
    1. remove exit code in selMotor.sh, simple bug just for test
    2. All arduino code into folder, then easy to compare and run
    [encoder32Test.ino, motorController32Test.ino]
2024-01-19 Update selMotor.sh
    Bug since arduino code move into subfolder. script needs to enter subfolder first.
2024-01-20 Tune178RPM motor
    1. Modify PWM calculation for 178RPM
    2. Reduce max rad/s
    3. Add curve fitting python code
    4. Reduce PWM 500 -> 300Hz
    5. Reduce PID gain 1/10
2024-01-20 Bug since arduino code move into subfolder. script needs to enter subfolder first.
    1. Fix wrong selDomain.sh, Remove unnecessary commands in selMotor.sh
    2. Set to default motor type 60RPM
    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
2024-01-24 Delete several arduino code
    Delete several arduino code, hard to manage
2024-02-03 Use 1KHz PWM, and tune both motors
    1. 178RPM motor encoder ticks are different. 580, 620
    So use average value of 600
    2. Reduce PID gain, can't turn for 178RPM motor
    3. Change to volatile left_wheel_tick_count, right_wheel_tick_count
    4. calc_vel_left_wheel, calc_vel_right_wheel -> calc_vel
    5. Delete buzzer beep if car reverse
    6. Remove wrap around fwhen calculate numOfTicks
    7. Add many measurement into encoder32Test.ino
    [encoder32Test.ino, motorController32Test.ino, motorEncExtraRos32.ino]
2024-02-03 Update odomPublisher.py
    1. Fix a typo, cos(dt) -> os(dth)
    2. dt -> timer tick
    3. Use quaternion_from_euler from omo_r1mini-foxy
2024-02-06 Tune 178RPM again, Go back to previous odomPublish
    1. Go back to original odomPublisher, but still fixed an error
    2. curve fit with Vright, then calculate offset
    3. Go back to 620 for 178RPM TPR
    [encoder32Test.ino, motorController32Test.ino, motorEncExtraRos32.ino]
2024-02-21 Change version 0.9.1 -> 1.0.0
    1. Change version 0.9.1 -> 1.0.0
    Change author and maintainer
    2. Port omo r1 mini odom code
    3. Rename monicar2_lidar.lua -> lidar.lua
    4. Delete unused monicar2_lidar.ymal, monicar2_mcu.yaml
2024-03-01 Add 6050 calibration and check code
    1. Apply new board calibration value
    2. Add 6050 calibration and check code
2024-03-02 Update motorEncExtraRos32.ino
    Add define to print Quaternion
